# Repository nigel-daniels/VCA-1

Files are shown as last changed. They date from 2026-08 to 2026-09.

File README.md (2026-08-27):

# VCA 1

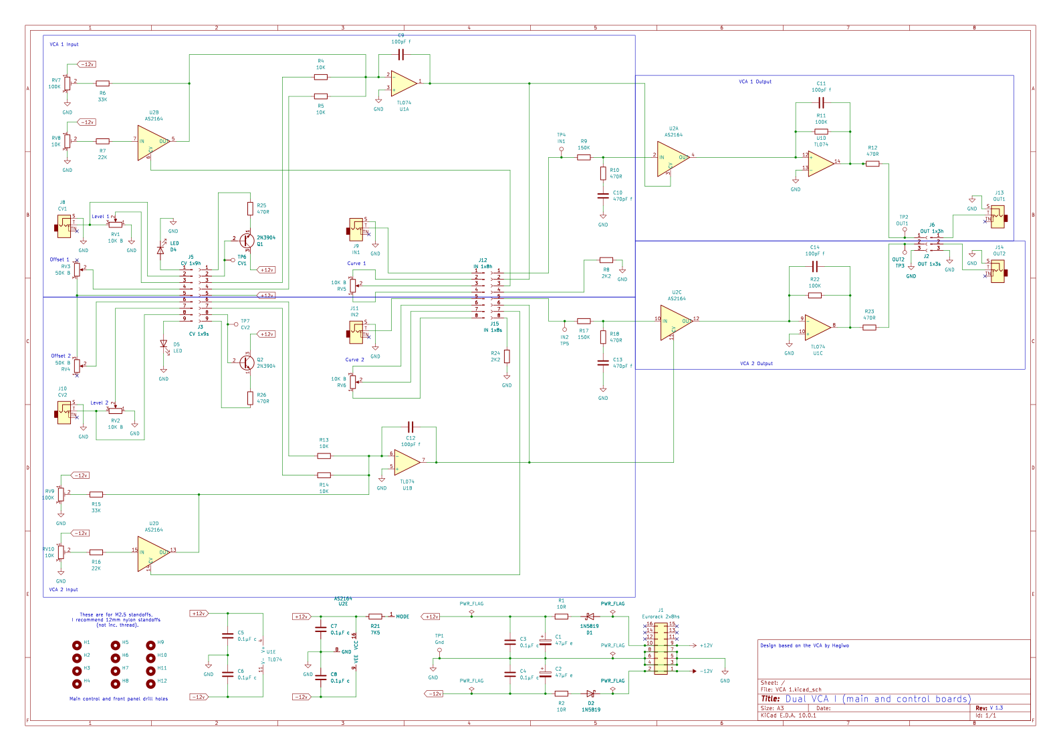
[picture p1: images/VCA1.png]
Board schematic


This dual VCA AS2164 VCA is based on the Hagiwo's [Dual VCA Rev.2](https://note.com/solder_state/n/nd82c027d0597). 

To calibrate the range for each VCA (Where *n* is the VCA number) using the test points[^1]:

1. Set the Offset pot to be closed. Now measure at CV*n* and ensure it is at 0V, now measure at OUT*n* and adjust the 100k (104) trim pot until the output is 0.
2. Still with the Offset pot closed, measure CV*n* and ensure it is at 5V, now check the IN*n* V and record it, next measure OUT*n* and adjust the 10K (103) trimpot and ensure the OUT*n* V == IN*n* V[^2]. NB: You can set it to more or less if you like but less than x0.1 or more than x5 makes the VCA hard to use.

[^1]: Don't forget to plug a jack in the OUT*n* socket or it will be connected to GND.
[^2]: This could be the inverse of the IN*n* V i.e. -V.

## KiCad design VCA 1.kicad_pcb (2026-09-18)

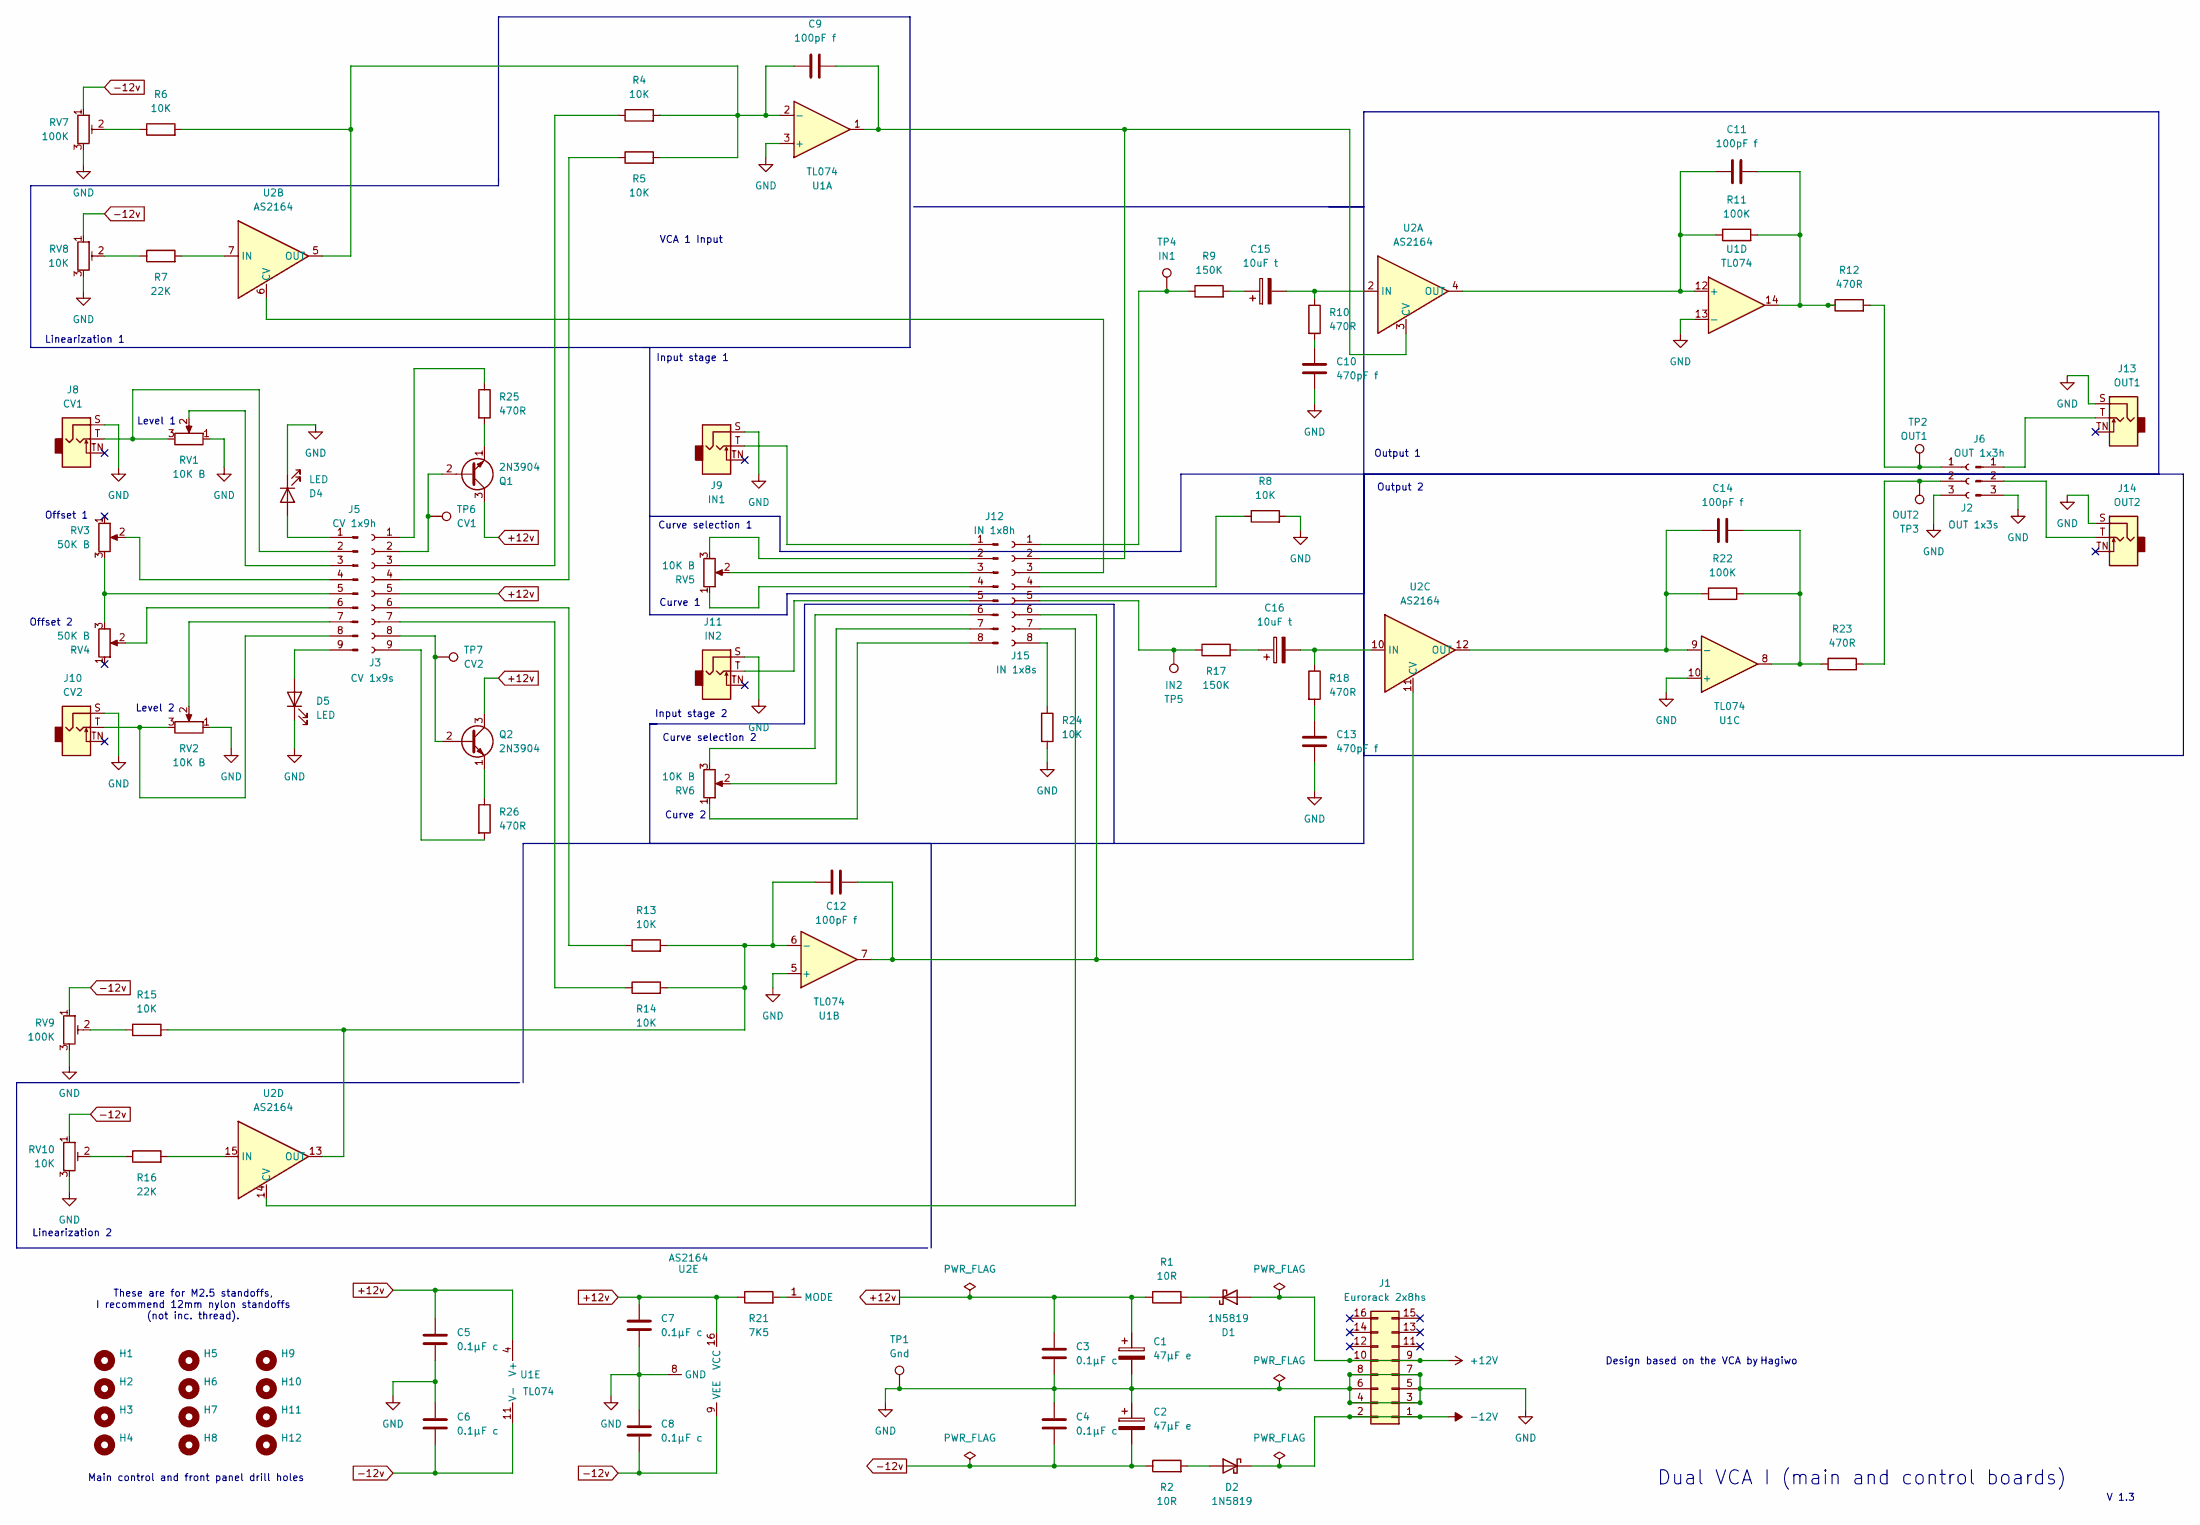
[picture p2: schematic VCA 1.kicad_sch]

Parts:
C1, C2: 47μF e; CP_Radial_D5.0mm_P2.50mm
C3, C4, C5, C6, C7, C8: 0.1μF c; C_Disc_D4.7mm_W2.5mm_P5.00mm
C9, C11, C12, C14: 100pF f; C_Rect_L7.2mm_W2.5mm_P5.00mm
C10, C13: 470pF f; C_Rect_L7.2mm_W2.5mm_P5.00mm
C15, C16: 10uF t; CP_Radial_Tantal_D4.5mm_P2.50mm
D1, D2: 1N5819; D_DO-41_SOD81_P10.16mm_Horizontal
D4, D5: LED; LED_D3.0mm_FlatTop
H1, H2, H3, H4, H5, H6, H7, H8: MountingHole_2.7mm_M2.5
H9, H10, H11, H12: MountingHole_3.2mm_M3
J1: Eurorack 2x8hs; IDC-Header_2x08_P2.54mm_Vertical
J2: OUT 1x3s; PinSocket_1x03_P2.54mm_Vertical
J3: CV 1x9s; PinSocket_1x09_P2.54mm_Vertical
J5: CV 1x9h; PinHeader_1x09_P2.54mm_Vertical
J6: OUT 1x3h; PinHeader_1x03_P2.54mm_Vertical
J8: CV1; Jack_3.5mm_QingPu_WQP-PJ398SM_Vertical_CircularHoles
J9: IN1; Jack_3.5mm_QingPu_WQP-PJ398SM_Vertical_CircularHoles
J10: CV2; Jack_3.5mm_QingPu_WQP-PJ398SM_Vertical_CircularHoles
J11: IN2; Jack_3.5mm_QingPu_WQP-PJ398SM_Vertical_CircularHoles
J12: IN 1x8h; PinHeader_1x08_P2.54mm_Vertical
J13: OUT1; Jack_3.5mm_QingPu_WQP-PJ398SM_Vertical_CircularHoles
J14: OUT2; Jack_3.5mm_QingPu_WQP-PJ398SM_Vertical_CircularHoles
J15: IN 1x8s; PinSocket_1x08_P2.54mm_Vertical
Q1, Q2: 2N3904; TO-92_Inline_Wide
R1, R2: 10R; R_Axial_DIN0204_L3.6mm_D1.6mm_P2.54mm_Vertical
R4, R5, R6, R13, R14, R15: 10K; R_Axial_DIN0204_L3.6mm_D1.6mm_P7.62mm_Horizontal
R7: 22K; R_Axial_DIN0204_L3.6mm_D1.6mm_P7.62mm_Horizontal
R8, R24: 10K; R_Axial_DIN0204_L3.6mm_D1.6mm_P2.54mm_Vertical
R9, R17: 150K; R_Axial_DIN0204_L3.6mm_D1.6mm_P2.54mm_Vertical
R10, R18, R25, R26: 470R; R_Axial_DIN0204_L3.6mm_D1.6mm_P2.54mm_Vertical
R11, R22: 100K; R_Axial_DIN0204_L3.6mm_D1.6mm_P2.54mm_Vertical
R12, R23: 470R; R_Axial_DIN0204_L3.6mm_D1.6mm_P7.62mm_Horizontal
R16: 22K; R_Axial_DIN0204_L3.6mm_D1.6mm_P2.54mm_Vertical
R21: 7K5; R_Axial_DIN0204_L3.6mm_D1.6mm_P7.62mm_Horizontal
RV1, RV2, RV5, RV6: 10K B; Potentiometer_Alps_RK09L_Single_Vertical
RV3, RV4: 50K B; Potentiometer_Alps_RK09L_Single_Vertical
RV7, RV9: 100K; Potentiometer_Bourns_3296X_Horizontal
RV8, RV10: 10K; Potentiometer_Bourns_3296X_Horizontal
TP1: Gnd; TestPoint_Loop_D2.50mm_Drill1.0mm
TP2: OUT1; TestPoint_Loop_D2.50mm_Drill1.0mm
TP3: OUT2; TestPoint_Loop_D2.50mm_Drill1.0mm
TP4: IN1; TestPoint_Loop_D2.50mm_Drill1.0mm
TP5: IN2; TestPoint_Loop_D2.50mm_Drill1.0mm
TP6: CV1; TestPoint_Loop_D2.50mm_Drill1.0mm
TP7: CV2; TestPoint_Loop_D2.50mm_Drill1.0mm
U1: TL074; DIP-14_W7.62mm
U2: AS2164; DIP-16_W7.62mm

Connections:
+12V: D1.2 (A), J1.9, J1.10
+12v: C1.1, C3.1, C5.1, C7.1, J3.5, Q1.3 (C), Q2.3 (C), R1.1, R21.1, U1.4 (V+), U2.16 (VCC)
-12V: D2.1 (K), J1.1, J1.2
-12v: C2.2, C4.2, C6.2, C8.2, R2.1, RV7.1, RV8.1, RV9.1, RV10.1, U1.11 (V-), U2.9 (VEE)
GND: C1.2, C2.1, C3.2, C4.1, C5.2, C6.1, C7.2, C8.1, C10.2, C13.2, D4.1 (K), D5.1 (K), J1.3, J1.4, J1.5, J1.6, J1.7, J1.8, J2.3, J6.3, J8.S, J9.S, J10.S, J11.S, J13.S, J14.S, R8.2, R24.2, RV1.1, RV2.1, RV7.3, RV8.3, RV9.3, RV10.3, TP1.1 (1_1), U1.3 (+), U1.5 (+), U1.10 (+), U1.13 (-), U2.8 (GND)
unnamed: C10.1, R10.2
unnamed: C11.2, R11.2, R12.1, U1.14
unnamed: C13.1, R18.2
unnamed: C14.2, R22.2, R23.1, U1.8
unnamed: C15.1, R9.2
unnamed: C16.1, R17.2
unnamed: D1.1 (K), R1.2
unnamed: D2.2 (A), R2.2
unnamed: D4.2 (A), J5.1
unnamed: D5.2 (A), J5.9
unnamed: J2.1, R12.2, TP2.1 (1_1)
unnamed: J2.2, R23.2, TP3.1 (1_1)
unnamed: J3.1, R25.1
unnamed: J3.2, Q1.2 (B), TP6.1 (1_1)
unnamed: J3.3, R4.1
unnamed: J3.4, R5.1
unnamed: J3.6, R13.1
unnamed: J3.7, R14.1
unnamed: J3.8, Q2.2 (B), TP7.1 (1_1)
unnamed: J3.9, R26.2
unnamed: J5.2, J8.T, RV1.3
unnamed: J5.3, RV1.2
unnamed: J5.4, RV3.2
unnamed: J5.5, RV3.3, RV4.3
unnamed: J5.6, RV4.2
unnamed: J5.7, RV2.2
unnamed: J5.8, J10.T, RV2.3
unnamed: J6.1, J13.T
unnamed: J6.2, J14.T
unnamed: J9.T, J12.1
unnamed: J12.2, RV5.3
unnamed: J12.3, RV5.2
unnamed: J12.4, RV5.1
unnamed: J11.T, J12.5
unnamed: J12.6, RV6.3
unnamed: J12.7, RV6.2
unnamed: J12.8, RV6.1
unnamed: J15.1, R9.1, TP4.1 (1_1)
unnamed: C9.2, J15.2, U1.1, U2.3 (CV)
unnamed: J15.3, U2.6 (CV)
unnamed: J15.4, R8.1
unnamed: J15.5, R17.1, TP5.1 (1_1)
unnamed: C12.2, J15.6, U1.7, U2.11 (CV)
unnamed: J15.7, U2.14 (CV)
unnamed: J15.8, R24.1
unnamed: Q1.1 (E), R25.2
unnamed: Q2.1 (E), R26.1
unnamed: R6.1, RV7.2
unnamed: R7.1, RV8.2
unnamed: R15.1, RV9.2
unnamed: R16.1, RV10.2
unnamed: C9.1, R4.2, R5.2, R6.2, U1.2 (-), U2.5 (OUT)
unnamed: C12.1, R13.2, R14.2, R15.2, U1.6 (-), U2.13 (OUT)
unnamed: C14.1, R22.1, U1.9 (-), U2.12 (OUT)
unnamed: C11.1, R11.1, U1.12 (+), U2.4 (OUT)
unnamed: C15.2, R10.1, U2.2 (IN)
unnamed: R7.2, U2.7 (IN)
unnamed: C16.2, R18.1, U2.10 (IN)
unnamed: R16.2, U2.15 (IN)
unnamed: R21.2, U2.1 (MODE)

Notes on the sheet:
Curve 2
Design based on the VCA by
Level 2
Linearization 2
Offset 2
Main control and front panel drill holes
Curve 1
Curve selection 1
V 1.3
Output 2
Input stage 1
Output 1
These are for M2.5 standoffs, I recommend 12mm nylon standoffs (not inc. thread).
Curve selection 2
Hagiwo
Linearization 1
Input stage 2
VCA 1 Input
Dual VCA I (main and control boards)
Offset 1
Level 1

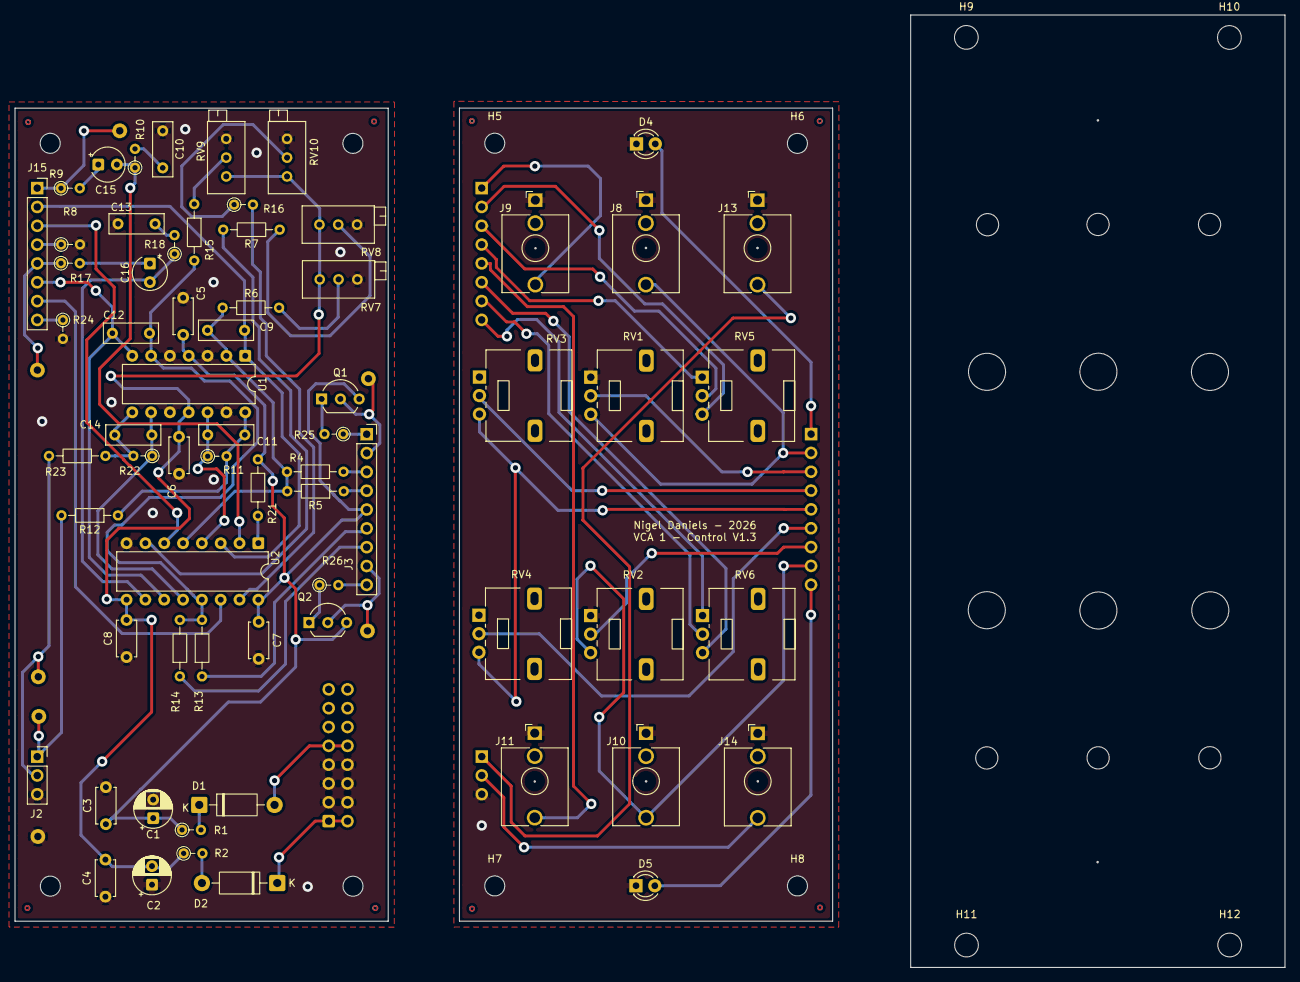
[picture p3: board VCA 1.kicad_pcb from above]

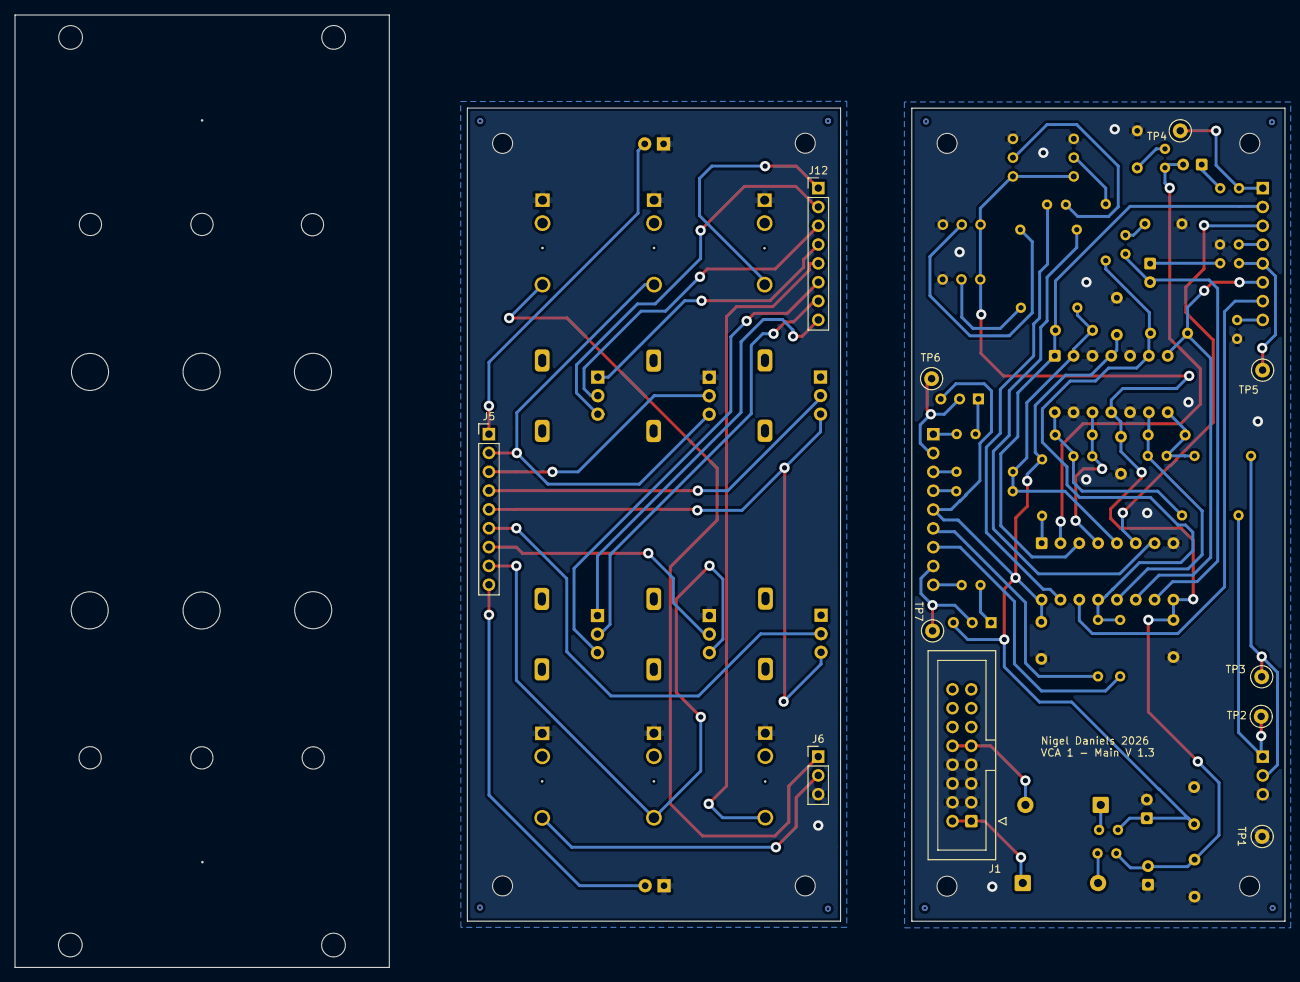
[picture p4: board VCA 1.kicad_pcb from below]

Board: 2 copper layers, 171.3 x 128.5 mm, 89 parts (11 on the bottom side), 65 nets.

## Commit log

2026-04-27 Updated schematic and .gitignore
    [VCA 1.kicad_sch]
2026-06-09 Added input LED
    [VCA 1.kicad_sch, controls.kicad_sch]
2026-06-12 Added test points and calibration information.
    [VCA 1.kicad_sch]
2026-06-16 Started on the PCB layout
    [VCA 1.kicad_pcb, VCA 1.kicad_sch, controls.kicad_sch]
2026-06-16 PCB passes EDC and panel cutouts done
    [VCA 1.kicad_pcb, VCA 1.kicad_sch]
2026-06-16 Connected ground islands
    [VCA 1.kicad_pcb]
2026-06-17 Updated to use CNC constraints
    [VCA 1.kicad_pcb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]
2026-06-17 Rotated PCB for CNC use
    [VCA 1.kicad_pcb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]
2026-06-18 Updated edge cuts for Flatcam
    [VCA 1.kicad_pcb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]
2026-06-20 Updated vias and reoriented design.
    [VCA 1.kicad_pcb]
2026-07-04 Created fabrication plots for photo-etching
    [VCA 1.kicad_pcb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]
2026-07-05 Added masks for vias
    [VCA 1.kicad_pcb]
2026-07-06 Added missing GND vias
    [VCA 1.kicad_pcb]
2026-07-16 Forgot panel pins are soldered on reverse
    [VCA 1.kicad_pcb, VCA 1.kicad_sch]
2026-07-16 Updated panel layout and plots.
    [VCA 1.kicad_pcb]
2026-08-06 Updated controls and added licence
    [VCA 1.kicad_pcb, controls.kicad_sch]
2026-08-07 Licence update and clean up
    [VCA 1-Edge_Cuts.gm1]
2026-08-11 Update README.md
    Updated calibration notes
2026-08-11 Updated versioning
    [VCA 1.kicad_pcb, VCA 1.kicad_sch, controls.kicad_sch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]
2026-08-11 Reoriented power and fixed flags
    [VCA 1.kicad_pcb, VCA 1.kicad_sch]
2026-08-11 Added alignment marks
    [VCA 1.kicad_pcb]
2026-08-12 Updated trim pot footprints
    [VCA 1.kicad_pcb, VCA 1.kicad_sch]
2026-08-27 Created custom AS2164 symbol, updated schematic, pcb and readme.
    [VCA 1.kicad_pcb, VCA 1.kicad_sch]
2026-08-27 Removed old schematics
    [VCA 1.kicad_sch, controls.kicad_sch, front_panel.kicad_sch]
2026-08-27 Updated schematic and image
    [VCA 1.kicad_sch]
2026-08-28 Noted linearization components
    [VCA 1.kicad_sch]
2026-09-11 New simulation, updated design after breadboard test.
    [VCA 1.kicad_pcb, VCA 1.kicad_sch]
2026-09-15 Updated curve values to match breadboard
    [VCA 1.kicad_pcb, VCA 1.kicad_sch]
2026-09-15 Removed uneeded resistor
    [VCA 1.kicad_pcb, VCA 1.kicad_sch]
2026-09-18 Reworked R values for 0-8V CV
    [VCA 1.kicad_pcb, VCA 1.kicad_sch]
2026-09-18 Updated Curve to GND R
    [VCA 1.kicad_pcb, VCA 1.kicad_sch]
2026-09-18 Returned Lin input RV to 10K
    [VCA 1.kicad_pcb, VCA 1.kicad_sch]
